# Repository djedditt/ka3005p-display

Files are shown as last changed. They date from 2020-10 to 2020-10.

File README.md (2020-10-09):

# ka3005p-display

This repository contains a KiCad project for a Korad KA3005P display driver, included are the schematic, pcb layout and gerber files. This board can replace the existing KA002_V3.x PCB in a Korad KA3005P (or KA3005D) power supply.

## Table of Contents

* [Bill of Materials (BOM)](#bom)
* [Pictures](#pictures)
* [License](#license)
* [Contact](#contact)

## Bill of Materials (BOM)

Below you'll find the bill of materials for this board. The original PCB comes with 4.0mm LEDs, but I went for 5.0mm because those are more readily available.

| ID | Designator | Description | Quantity |
|---|---|---|---|
|1|C1|Capacitor, Ceramic, 22uF, 25V, 10%, X7R, 0805|1|
|2|LED1, LED2|4-Digit 7-Segment LED Display, Red, Common Cathode, TH, 0.40"|2|
|3|R17, R18, R19, R20, R21|Resistor, 1k Ohm, 1%, 1/8 W, 0805|5|
|4|Q4, Q5, Q6, Q7, Q8|NPN Transistor, MMBT3904, SOT-23-3|5|
|5|D1, D2, D3, D4, D5, D6, D7, D8, D9, D10|LED, Red, TH, 4.0mm (or 5.0mm)|10|
|6|U18|Low Dropout Linear Regulator, AZ1117-3.3, SOT-223|1|
|7|R1, R2, R3, R4, R5, R6, R7, R8, R9, R10, R11, R12, R13, R14, R15, R16|Resistor, 330 Ohm, 5%, 1/4 W, 0805|16
|8|U1, U3| 8-Bit Shift Register, 74HC595, SOIC-16|2
|9|CON1| Female Header, 12-Pin (2x6), 2.54mm|1

## Pictures

The finished board:
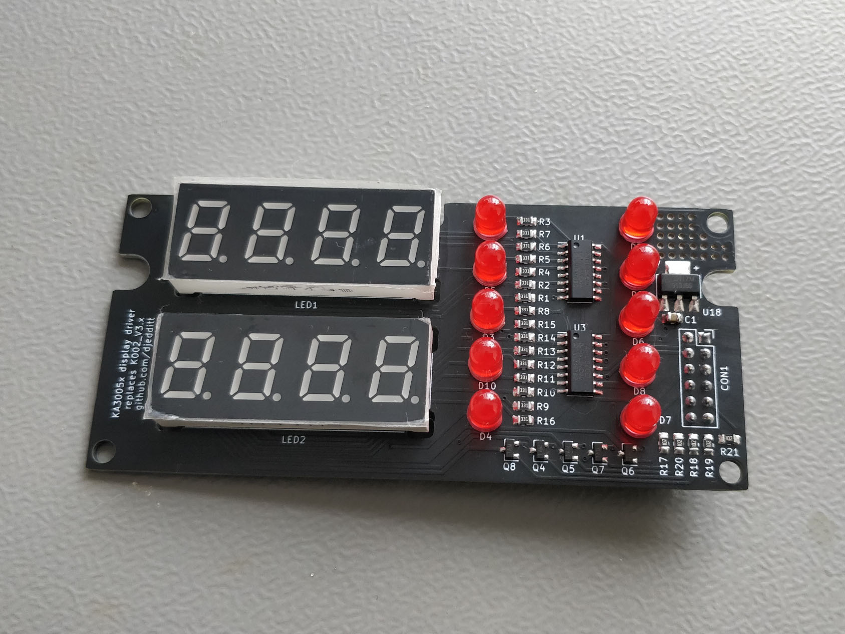
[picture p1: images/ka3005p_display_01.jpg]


Bare PCB (front and back):
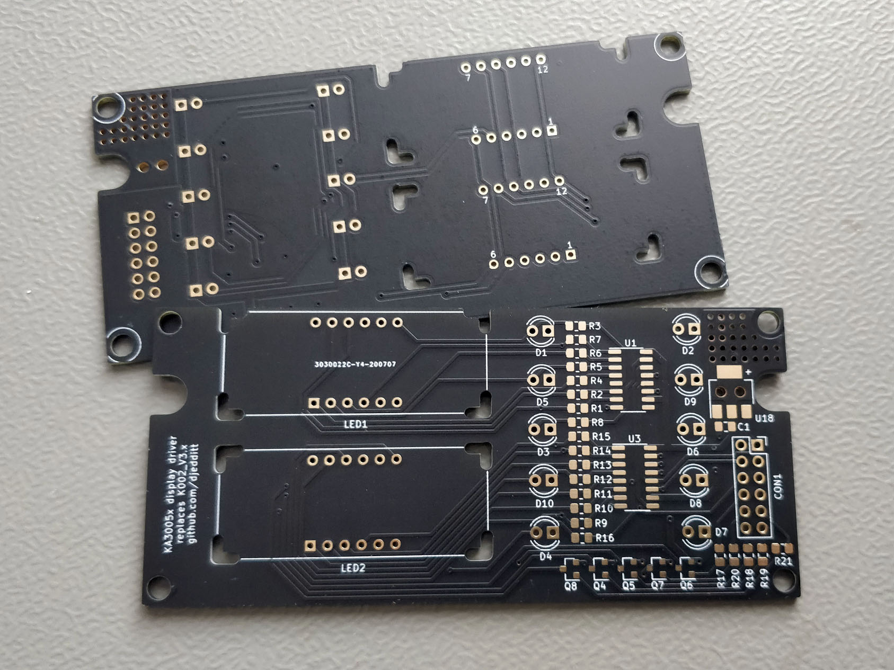
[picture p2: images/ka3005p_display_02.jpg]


## License

This work is licensed under a [Creative Commons Attribution 4.0 International
License][cc-by].

[cc-by]: http://creativecommons.org/licenses/by/4.0/ 

## Contact

You can e-mail me at: email-address

[email-address]: https://djedditt.net/github/email-address.gif

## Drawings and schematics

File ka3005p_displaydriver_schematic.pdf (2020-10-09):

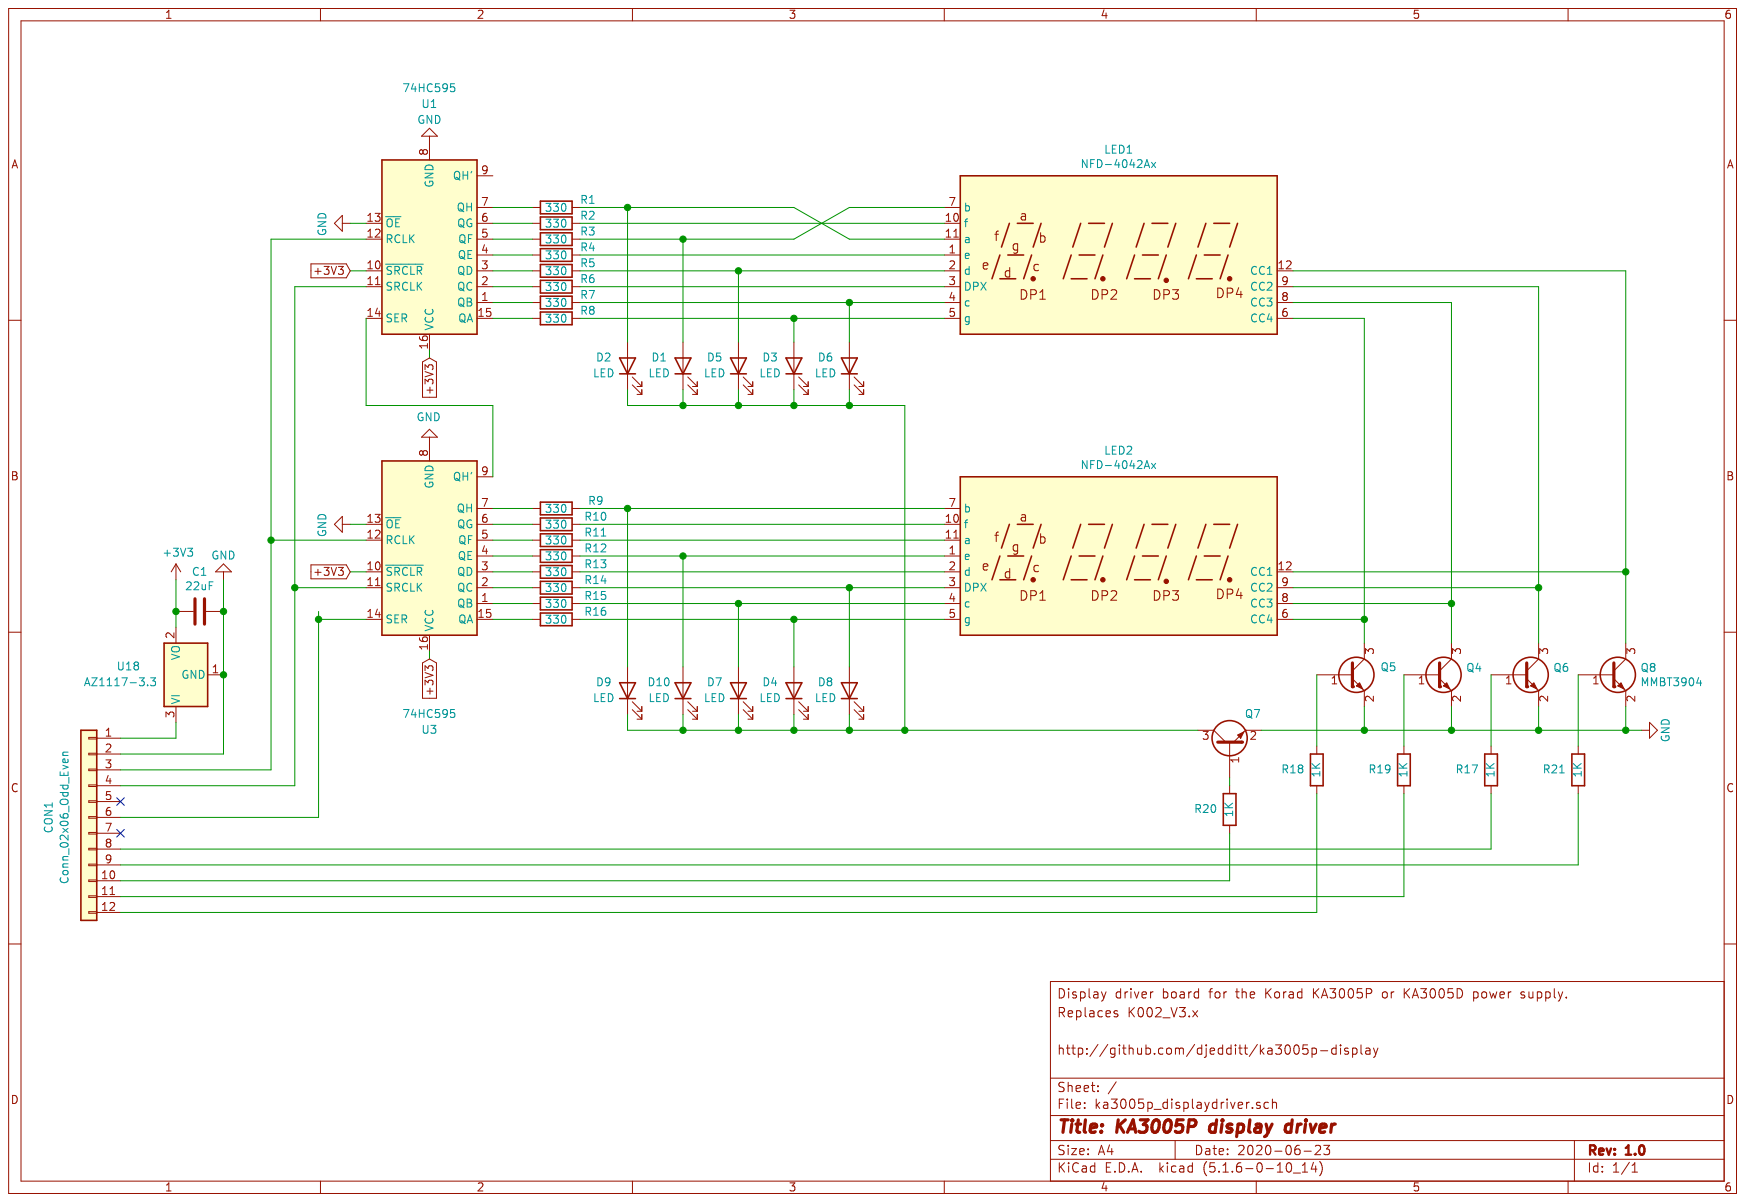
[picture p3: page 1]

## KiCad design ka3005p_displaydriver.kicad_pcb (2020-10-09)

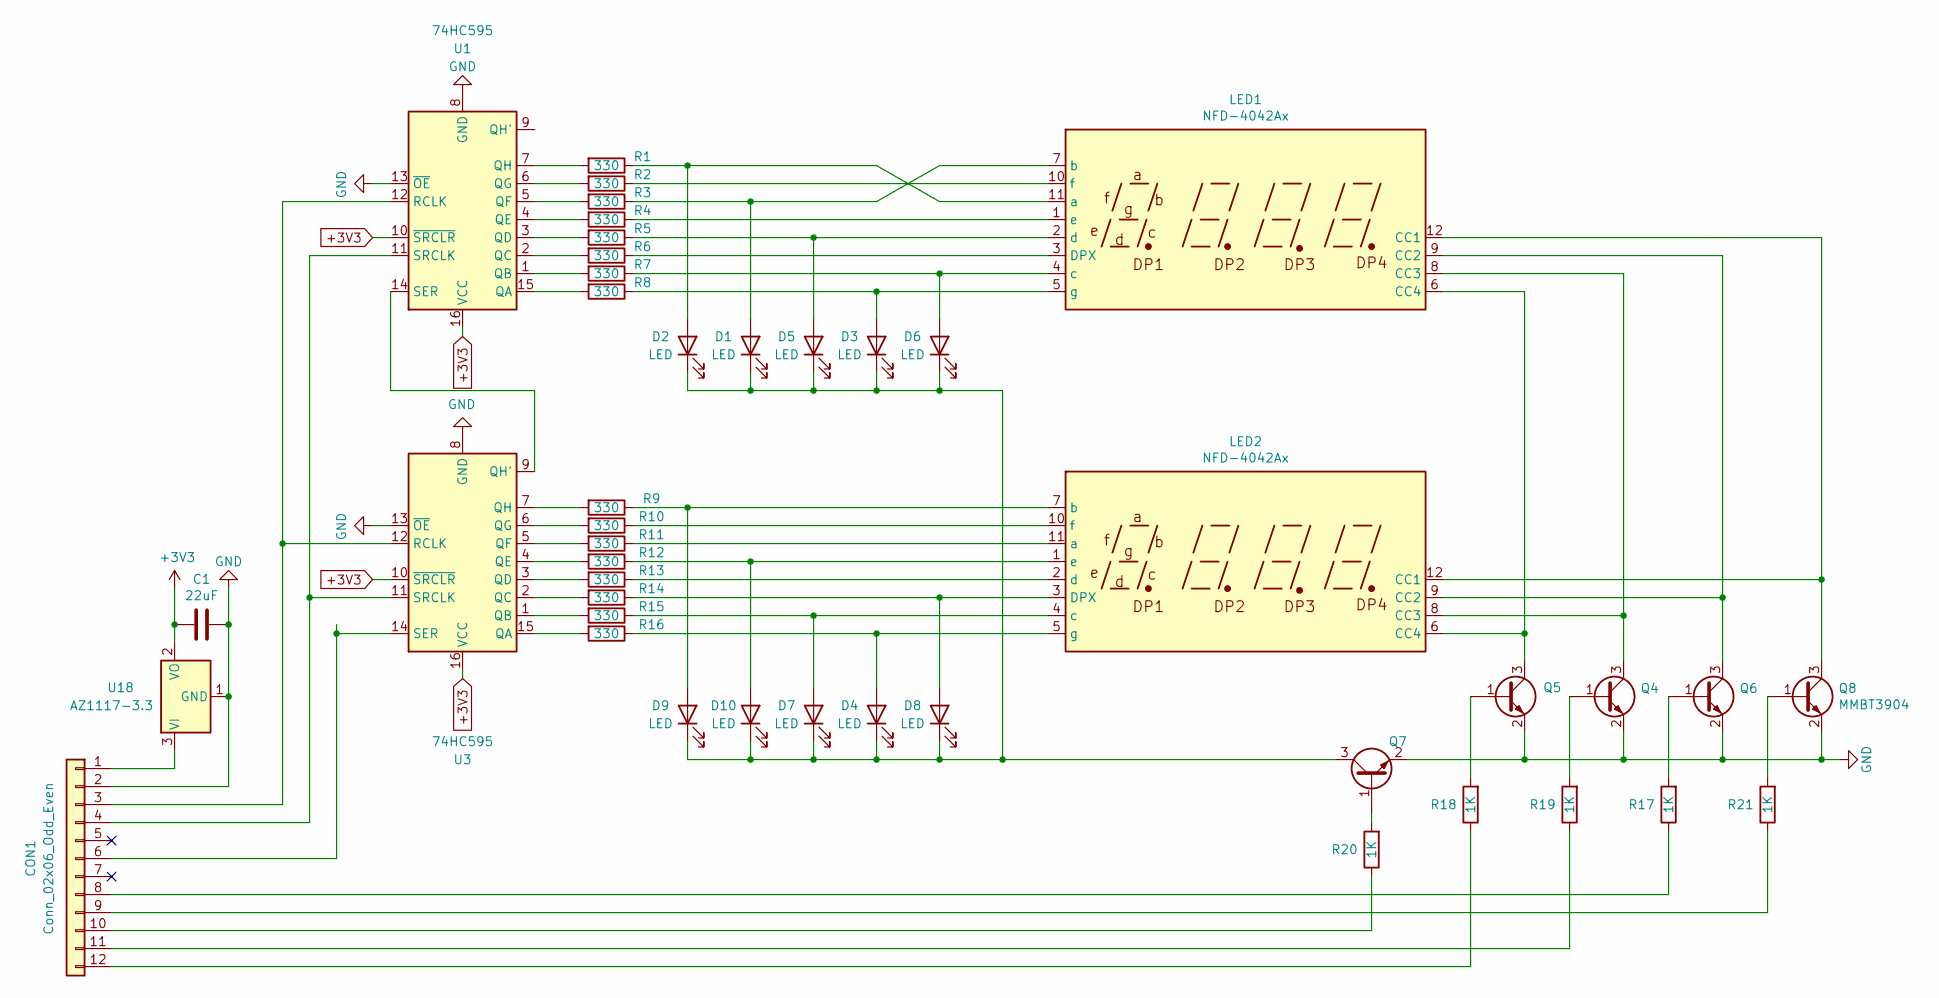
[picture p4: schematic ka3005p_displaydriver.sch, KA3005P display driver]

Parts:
C1: 22uF; C_0805_2012Metric_Pad1.15x1.40mm_HandSolder
CON1: Conn_02x06_Odd_Even; PinSocket_2x06_P2.54mm_Vertical
D1, D2, D3, D4, D5, D6, D7, D8, D9, D10: LED; LED_D4.0mm
LED1, LED2: NFD-4042Ax
Q4, Q5, Q6, Q7, Q8: MMBT3904; SOT-23
R1, R2, R3, R4, R5, R6, R7, R8, R9, R10, R11, R12, R13, R14, R15, R16: 330; R_0805_2012Metric_Pad1.15x1.40mm_HandSolder
R17, R18, R19, R20, R21: 1K; R_0805_2012Metric_Pad1.15x1.40mm_HandSolder
U1, U3: 74HC595; SOIC-16_3.9x9.9mm_P1.27mm
U18: AZ1117-3.3; SOT-223

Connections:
+3V3: C1.2, U1.10 (~SRCLR), U1.16 (VCC), U3.10 (~SRCLR), U3.16 (VCC), U18.2 (VO), U18.4
GND: C1.1, CON1.2, Q4.2 (E), Q5.2 (E), Q6.2 (E), Q7.2 (E), Q8.2 (E), U1.8 (GND), U1.13 (~OE), U3.8 (GND), U3.13 (~OE), U18.1 (GND)
unnamed: CON1.1, U18.3 (VI)
unnamed: CON1.3, U1.12 (RCLK), U3.12 (RCLK)
unnamed: CON1.4, U1.11 (SRCLK), U3.11 (SRCLK)
unnamed: CON1.6, U3.14 (SER)
unnamed: CON1.8, R17.1
unnamed: CON1.9, R21.1
unnamed: CON1.10, R20.1
unnamed: CON1.11, R19.1
unnamed: CON1.12, R18.1
unnamed: D1.1 (K), D2.1 (K), D3.1 (K), D4.1 (K), D5.1 (K), D6.1 (K), D7.1 (K), D8.1 (K), D9.1 (K), D10.1 (K), Q7.3 (C)
unnamed: D1.2 (A), LED1.7 (b), R3.1
unnamed: D2.2 (A), LED1.11 (a), R1.1
unnamed: D3.2 (A), LED1.5 (g), R8.1
unnamed: D4.2 (A), LED2.5 (g), R16.1
unnamed: D5.2 (A), LED1.2 (d), R5.1
unnamed: D6.2 (A), LED1.4 (c), R7.1
unnamed: D7.2 (A), LED2.4 (c), R15.1
unnamed: D8.2 (A), LED2.3 (DPX), R14.1
unnamed: D9.2 (A), LED2.7 (b), R9.1
unnamed: D10.2 (A), LED2.1 (e), R12.1
unnamed: LED1.1 (e), R4.1
unnamed: LED1.3 (DPX), R6.1
unnamed: LED1.6 (CC4), LED2.6 (CC4), Q5.3 (C)
unnamed: LED1.8 (CC3), LED2.8 (CC3), Q4.3 (C)
unnamed: LED1.9 (CC2), LED2.9 (CC2), Q6.3 (C)
unnamed: LED1.10 (f), R2.1
unnamed: LED1.12 (CC1), LED2.12 (CC1), Q8.3 (C)
unnamed: LED2.2 (d), R13.1
unnamed: LED2.10 (f), R10.1
unnamed: LED2.11 (a), R11.1
unnamed: Q4.1 (B), R19.2
unnamed: Q5.1 (B), R18.2
unnamed: Q6.1 (B), R17.2
unnamed: Q7.1 (B), R20.2
unnamed: Q8.1 (B), R21.2
unnamed: R1.2, U1.7 (QH)
unnamed: R2.2, U1.6 (QG)
unnamed: R3.2, U1.5 (QF)
unnamed: R4.2, U1.4 (QE)
unnamed: R5.2, U1.3 (QD)
unnamed: R6.2, U1.2 (QC)
unnamed: R7.2, U1.1 (QB)
unnamed: R8.2, U1.15 (QA)
unnamed: R9.2, U3.7 (QH)
unnamed: R10.2, U3.6 (QG)
unnamed: R11.2, U3.5 (QF)
unnamed: R12.2, U3.4 (QE)
unnamed: R13.2, U3.3 (QD)
unnamed: R14.2, U3.2 (QC)
unnamed: R15.2, U3.1 (QB)
unnamed: R16.2, U3.15 (QA)
unnamed: U1.14 (SER), U3.9 (QH')

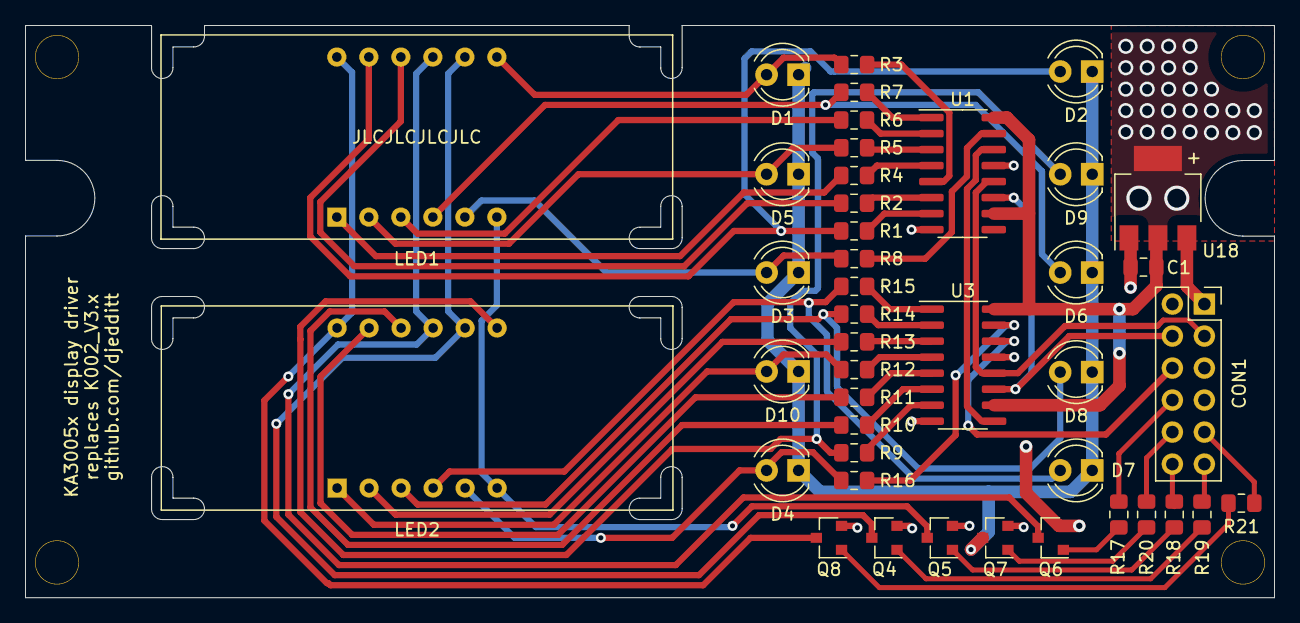
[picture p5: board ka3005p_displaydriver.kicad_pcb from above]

Board: 2 copper layers, 99.1 x 45.4 mm, 43 parts (0 on the bottom side), 54 nets.
